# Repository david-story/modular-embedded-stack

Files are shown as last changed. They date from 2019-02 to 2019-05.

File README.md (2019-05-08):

# modular-embedded-stack

Credit card sized modular embedded stackable boards that was designed for fun for a microprocessor / 
microcontroller class. Base board is a microcontroller board that supports a thru-hole or smd PIC18F45K20 chip,
depending on which board you select. Daughter boards that are currently implemented have sensors and peripheals
that the user can interact with. 

The following is current included in the files:
- Board and schematic for thru-hole microcontroller
- Board and schematic for SMD microcontroller
- Board and schematic sensor daughter board

The following will be created in the future:
- Board and schematic for communication daughter board
- Other daughter boards and modules.

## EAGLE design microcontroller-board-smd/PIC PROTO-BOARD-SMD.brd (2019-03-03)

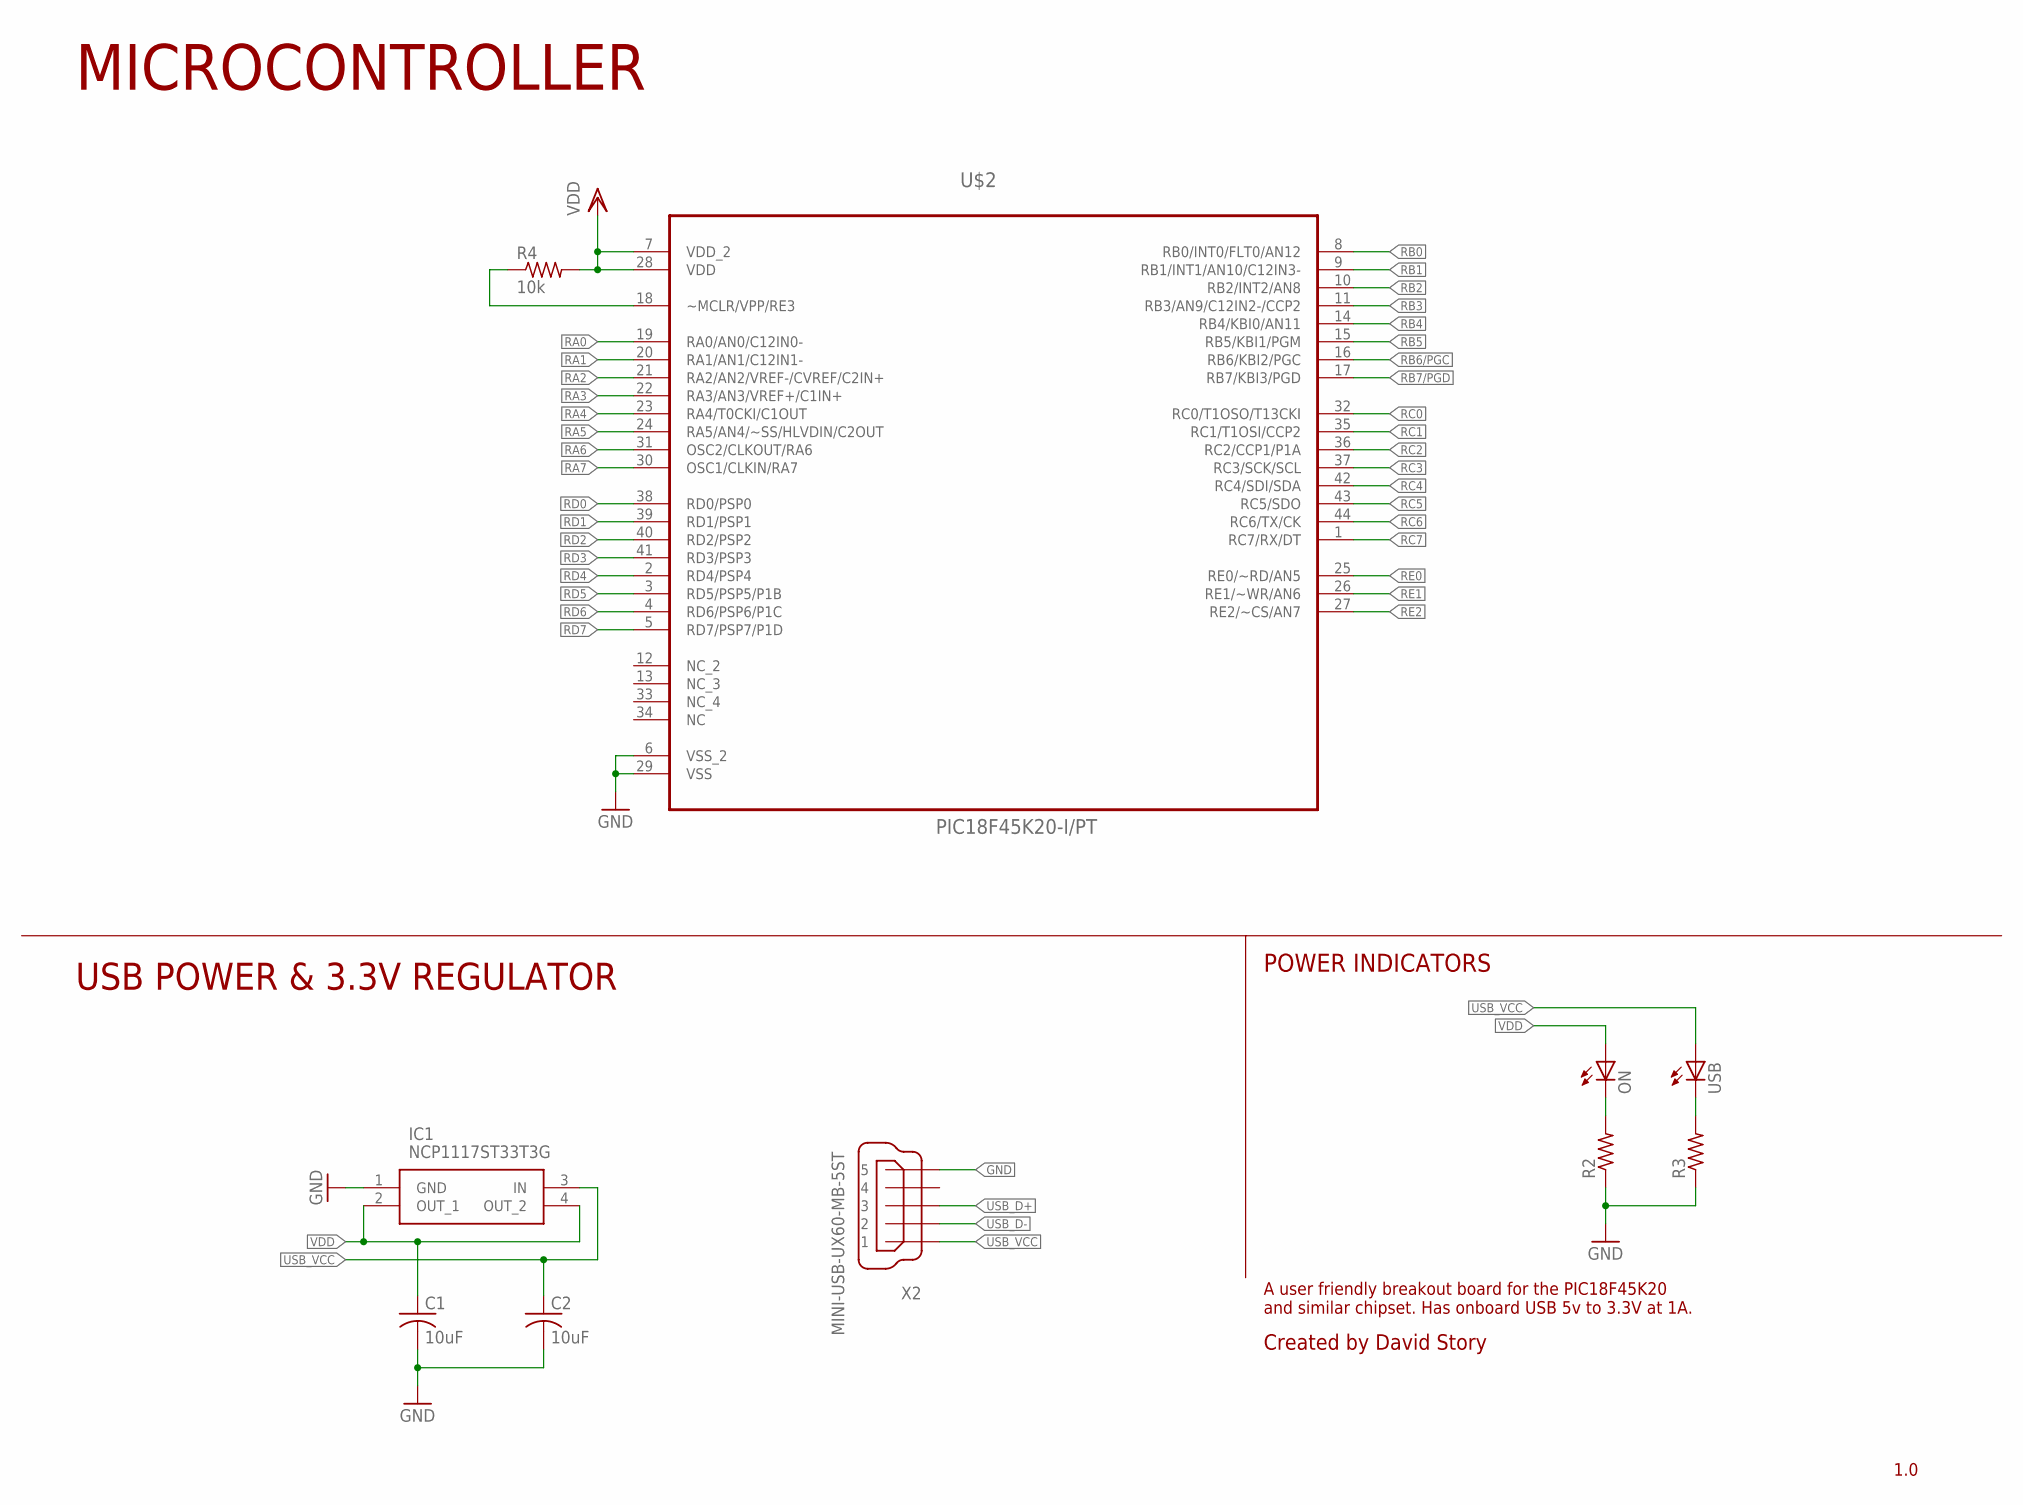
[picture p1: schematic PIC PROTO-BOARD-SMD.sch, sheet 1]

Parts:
C1, C2: 10uF; C0805
IC1: NCP1117ST33T3G; SOT230P700X180-4N
ON: LEDCHIP-LED0603; CHIP-LED0603
R2, R3: R-US_R0603; R0603
R4: 10k; R0805
U$2: PIC18F45K20-I/PT; QFP80P1200X1200X120-44N
USB: LEDCHIP-LED0603; CHIP-LED0603
X2: MINI-USB-UX60-MB-5ST; UX60-MB-5ST

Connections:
GND: C1.2, C2.2, IC1.1 (GND), R2.1, R3.1, U$2.6 (VSS_2), U$2.29 (VSS), X2.5; also elsewhere on the board
MCLR: R4.1, U$2.18 (~MCLR/VPP/RE3); also elsewhere on the board
ON_CATHODE: ON.C, R2.2
RA0: U$2.19 (RA0/AN0/C12IN0-); also elsewhere on the board
RA1: U$2.20 (RA1/AN1/C12IN1-); also elsewhere on the board
RA2: U$2.21 (RA2/AN2/VREF-/CVREF/C2IN+); also elsewhere on the board
RA3: U$2.22 (RA3/AN3/VREF+/C1IN+); also elsewhere on the board
RA4: U$2.23 (RA4/T0CKI/C1OUT); also elsewhere on the board
RA5: U$2.24 (RA5/AN4/~SS/HLVDIN/C2OUT); also elsewhere on the board
RA6: U$2.31 (OSC2/CLKOUT/RA6); also elsewhere on the board
RA7: U$2.30 (OSC1/CLKIN/RA7); also elsewhere on the board
RB0: U$2.8 (RB0/INT0/FLT0/AN12); also elsewhere on the board
RB1: U$2.9 (RB1/INT1/AN10/C12IN3-); also elsewhere on the board
RB2: U$2.10 (RB2/INT2/AN8); also elsewhere on the board
RB3: U$2.11 (RB3/AN9/C12IN2-/CCP2); also elsewhere on the board
RB4: U$2.14 (RB4/KBI0/AN11); also elsewhere on the board
RB5: U$2.15 (RB5/KBI1/PGM); also elsewhere on the board
RB6/PGC: U$2.16 (RB6/KBI2/PGC); also elsewhere on the board
RB7/PGD: U$2.17 (RB7/KBI3/PGD); also elsewhere on the board
RC0: U$2.32 (RC0/T1OSO/T13CKI); also elsewhere on the board
RC1: U$2.35 (RC1/T1OSI/CCP2); also elsewhere on the board
RC2: U$2.36 (RC2/CCP1/P1A); also elsewhere on the board
RC3: U$2.37 (RC3/SCK/SCL); also elsewhere on the board
RC4: U$2.42 (RC4/SDI/SDA); also elsewhere on the board
RC5: U$2.43 (RC5/SDO); also elsewhere on the board
RC6: U$2.44 (RC6/TX/CK); also elsewhere on the board
RC7: U$2.1 (RC7/RX/DT); also elsewhere on the board
RD0: U$2.38 (RD0/PSP0); also elsewhere on the board
RD1: U$2.39 (RD1/PSP1); also elsewhere on the board
RD2: U$2.40 (RD2/PSP2); also elsewhere on the board
RD3: U$2.41 (RD3/PSP3); also elsewhere on the board
RD4: U$2.2 (RD4/PSP4); also elsewhere on the board
RD5: U$2.3 (RD5/PSP5/P1B); also elsewhere on the board
RD6: U$2.4 (RD6/PSP6/P1C); also elsewhere on the board
RD7: U$2.5 (RD7/PSP7/P1D); also elsewhere on the board
RE0: U$2.25 (RE0/~RD/AN5); also elsewhere on the board
RE1: U$2.26 (RE1/~WR/AN6); also elsewhere on the board
RE2: U$2.27 (RE2/~CS/AN7); also elsewhere on the board
USB_CATHODE: R3.2, USB.C
USB_D+: X2.3; also elsewhere on the board
USB_D-: X2.2; also elsewhere on the board
USB_VCC: C2.1, IC1.3 (IN), USB.A, X2.1; also elsewhere on the board
VDD: C1.1, IC1.2 (OUT_1), IC1.4 (OUT_2), ON.A, R4.2, U$2.7 (VDD_2), U$2.28 (VDD); also elsewhere on the board

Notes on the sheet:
Created by David Story
1.0
MICROCONTROLLER
USB POWER & 3.3V REGULATOR
POWER INDICATORS
A user friendly breakout board for the PIC18F45K20 and similar chipset. Has onboard USB 5v to 3.3V at 1A.

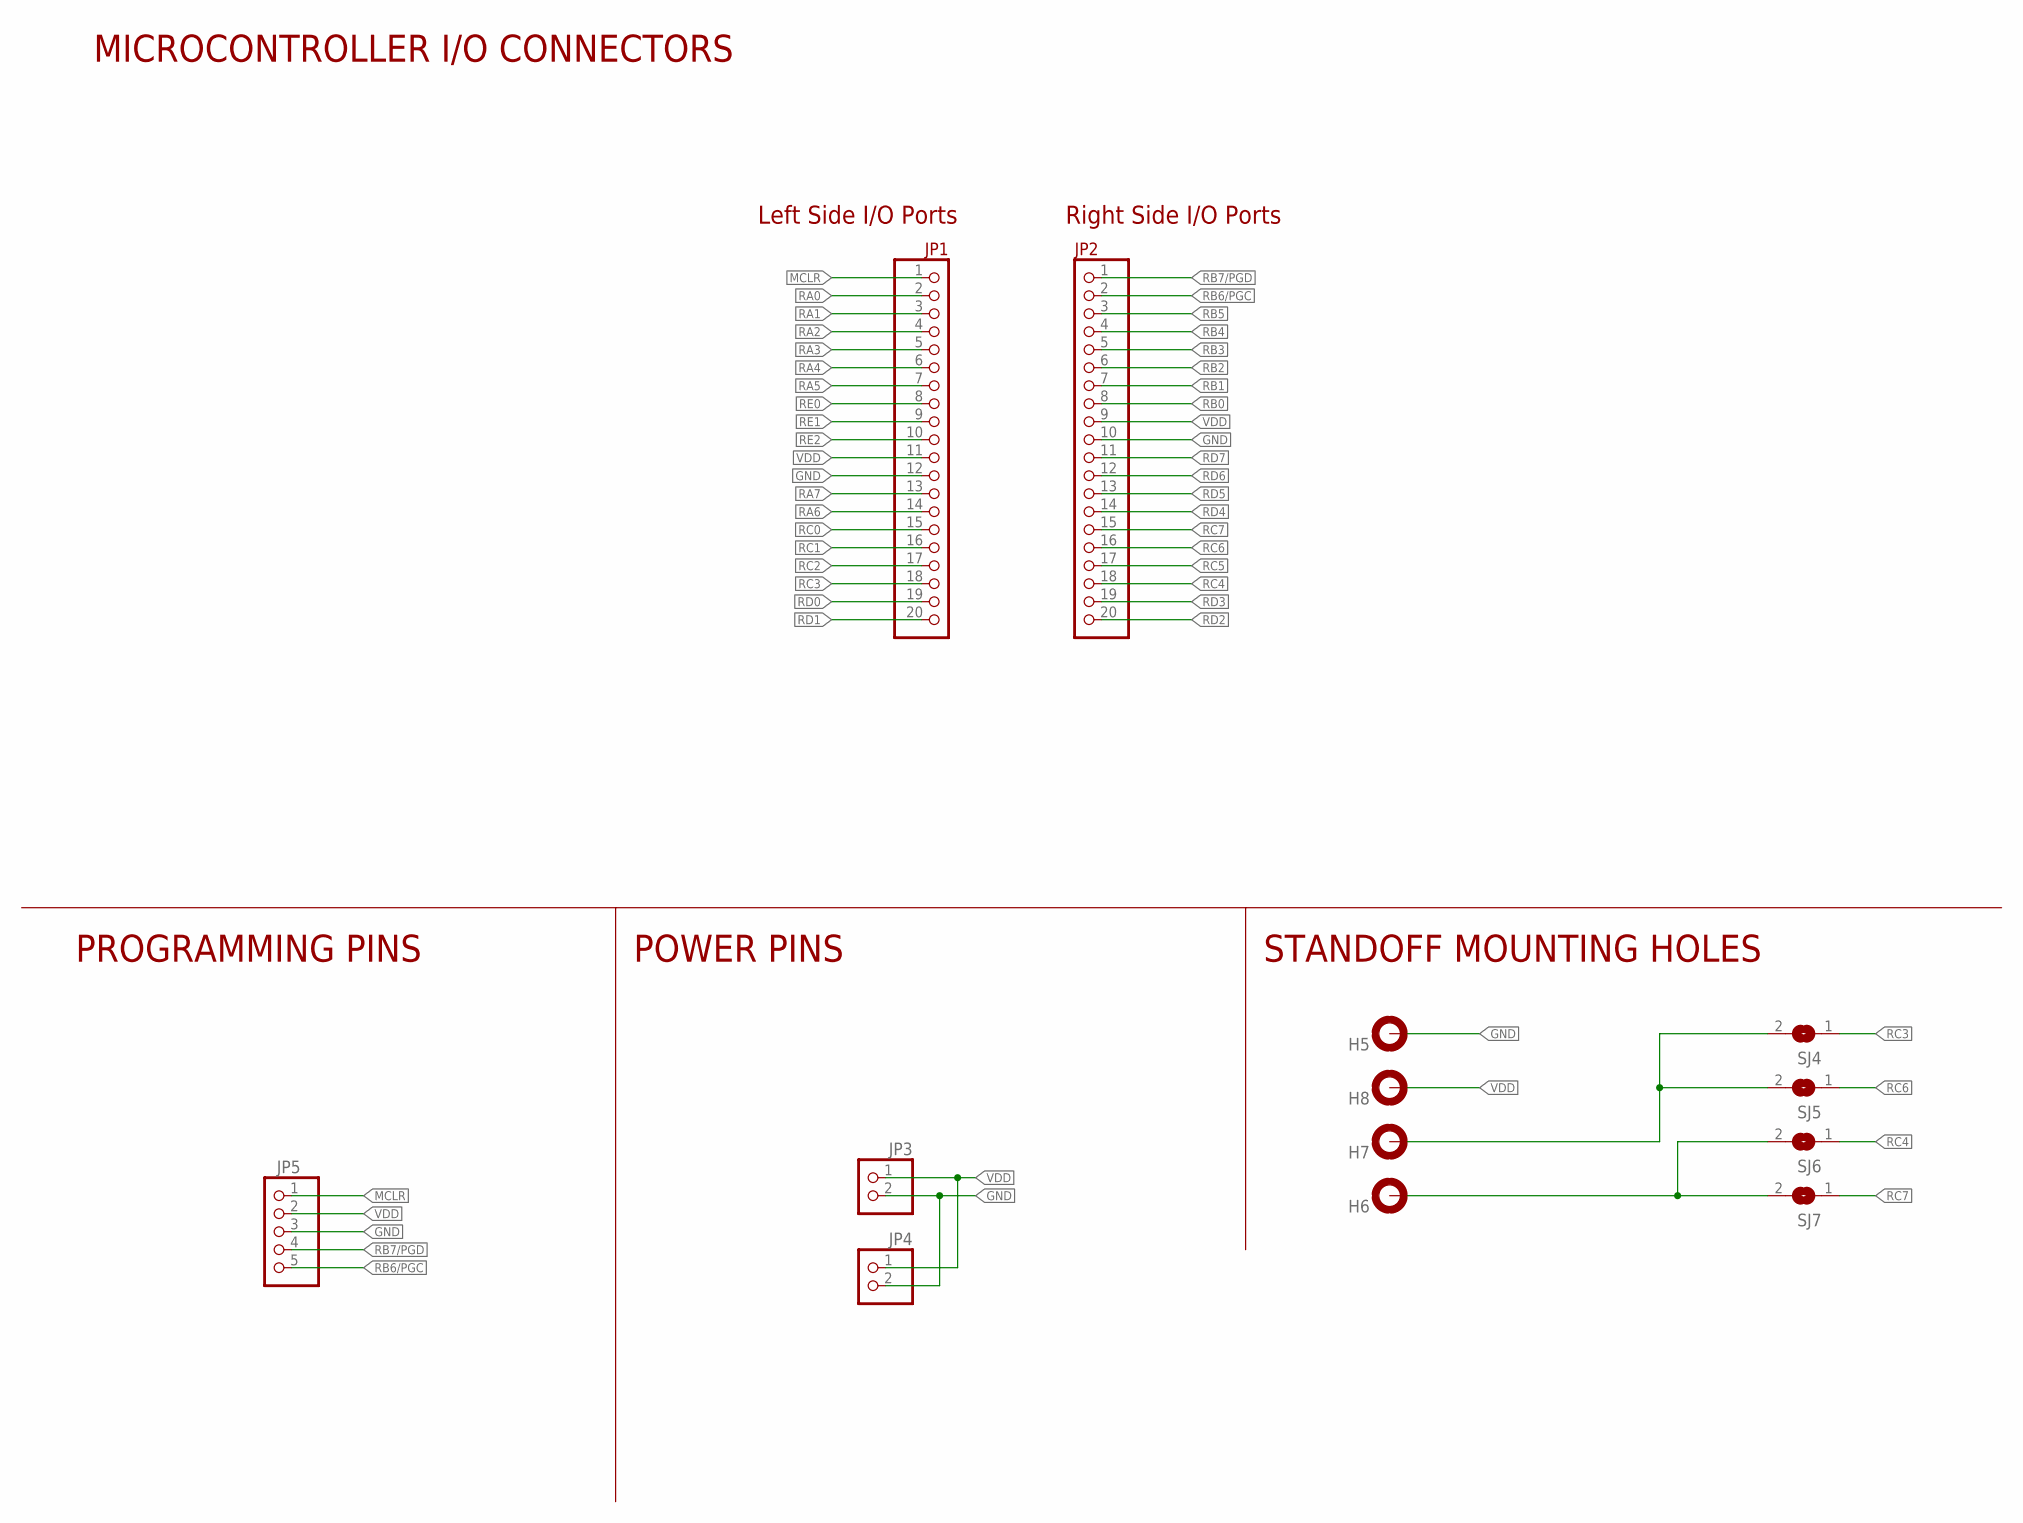
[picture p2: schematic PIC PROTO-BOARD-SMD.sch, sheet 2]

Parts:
H5, H6, H7, H8: MOUNT-PAD-ROUND3.3; 3,3-PAD
JP1, JP2: PINHD-1X20; 1X20
JP3, JP4: PINHD-1X2; 1X02
JP5: PINHD-1X5; 1X05
SJ4, SJ5, SJ6, SJ7: SJ

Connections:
COM_HOLE_1: H7.B3,3, SJ4.2, SJ5.2
COM_HOLE_2: H6.B3,3, SJ6.2, SJ7.2
GND: H5.B3,3, JP1.12, JP2.10, JP3.2, JP4.2, JP5.3; also elsewhere on the board
MCLR: JP1.1, JP5.1; also elsewhere on the board
RA0: JP1.2; also elsewhere on the board
RA1: JP1.3; also elsewhere on the board
RA2: JP1.4; also elsewhere on the board
RA3: JP1.5; also elsewhere on the board
RA4: JP1.6; also elsewhere on the board
RA5: JP1.7; also elsewhere on the board
RA6: JP1.14; also elsewhere on the board
RA7: JP1.13; also elsewhere on the board
RB0: JP2.8; also elsewhere on the board
RB1: JP2.7; also elsewhere on the board
RB2: JP2.6; also elsewhere on the board
RB3: JP2.5; also elsewhere on the board
RB4: JP2.4; also elsewhere on the board
RB5: JP2.3; also elsewhere on the board
RB6/PGC: JP2.2, JP5.5; also elsewhere on the board
RB7/PGD: JP2.1, JP5.4; also elsewhere on the board
RC0: JP1.15; also elsewhere on the board
RC1: JP1.16; also elsewhere on the board
RC2: JP1.17; also elsewhere on the board
RC3: JP1.18, SJ4.1; also elsewhere on the board
RC4: JP2.18, SJ6.1; also elsewhere on the board
RC5: JP2.17; also elsewhere on the board
RC6: JP2.16, SJ5.1; also elsewhere on the board
RC7: JP2.15, SJ7.1; also elsewhere on the board
RD0: JP1.19; also elsewhere on the board
RD1: JP1.20; also elsewhere on the board
RD2: JP2.20; also elsewhere on the board
RD3: JP2.19; also elsewhere on the board
RD4: JP2.14; also elsewhere on the board
RD5: JP2.13; also elsewhere on the board
RD6: JP2.12; also elsewhere on the board
RD7: JP2.11; also elsewhere on the board
RE0: JP1.8; also elsewhere on the board
RE1: JP1.9; also elsewhere on the board
RE2: JP1.10; also elsewhere on the board
VDD: H8.B3,3, JP1.11, JP2.9, JP3.1, JP4.1, JP5.2; also elsewhere on the board

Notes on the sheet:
Left Side I/O Ports
Right Side I/O Ports
PROGRAMMING PINS
POWER PINS
STANDOFF MOUNTING HOLES
MICROCONTROLLER I/O CONNECTORS

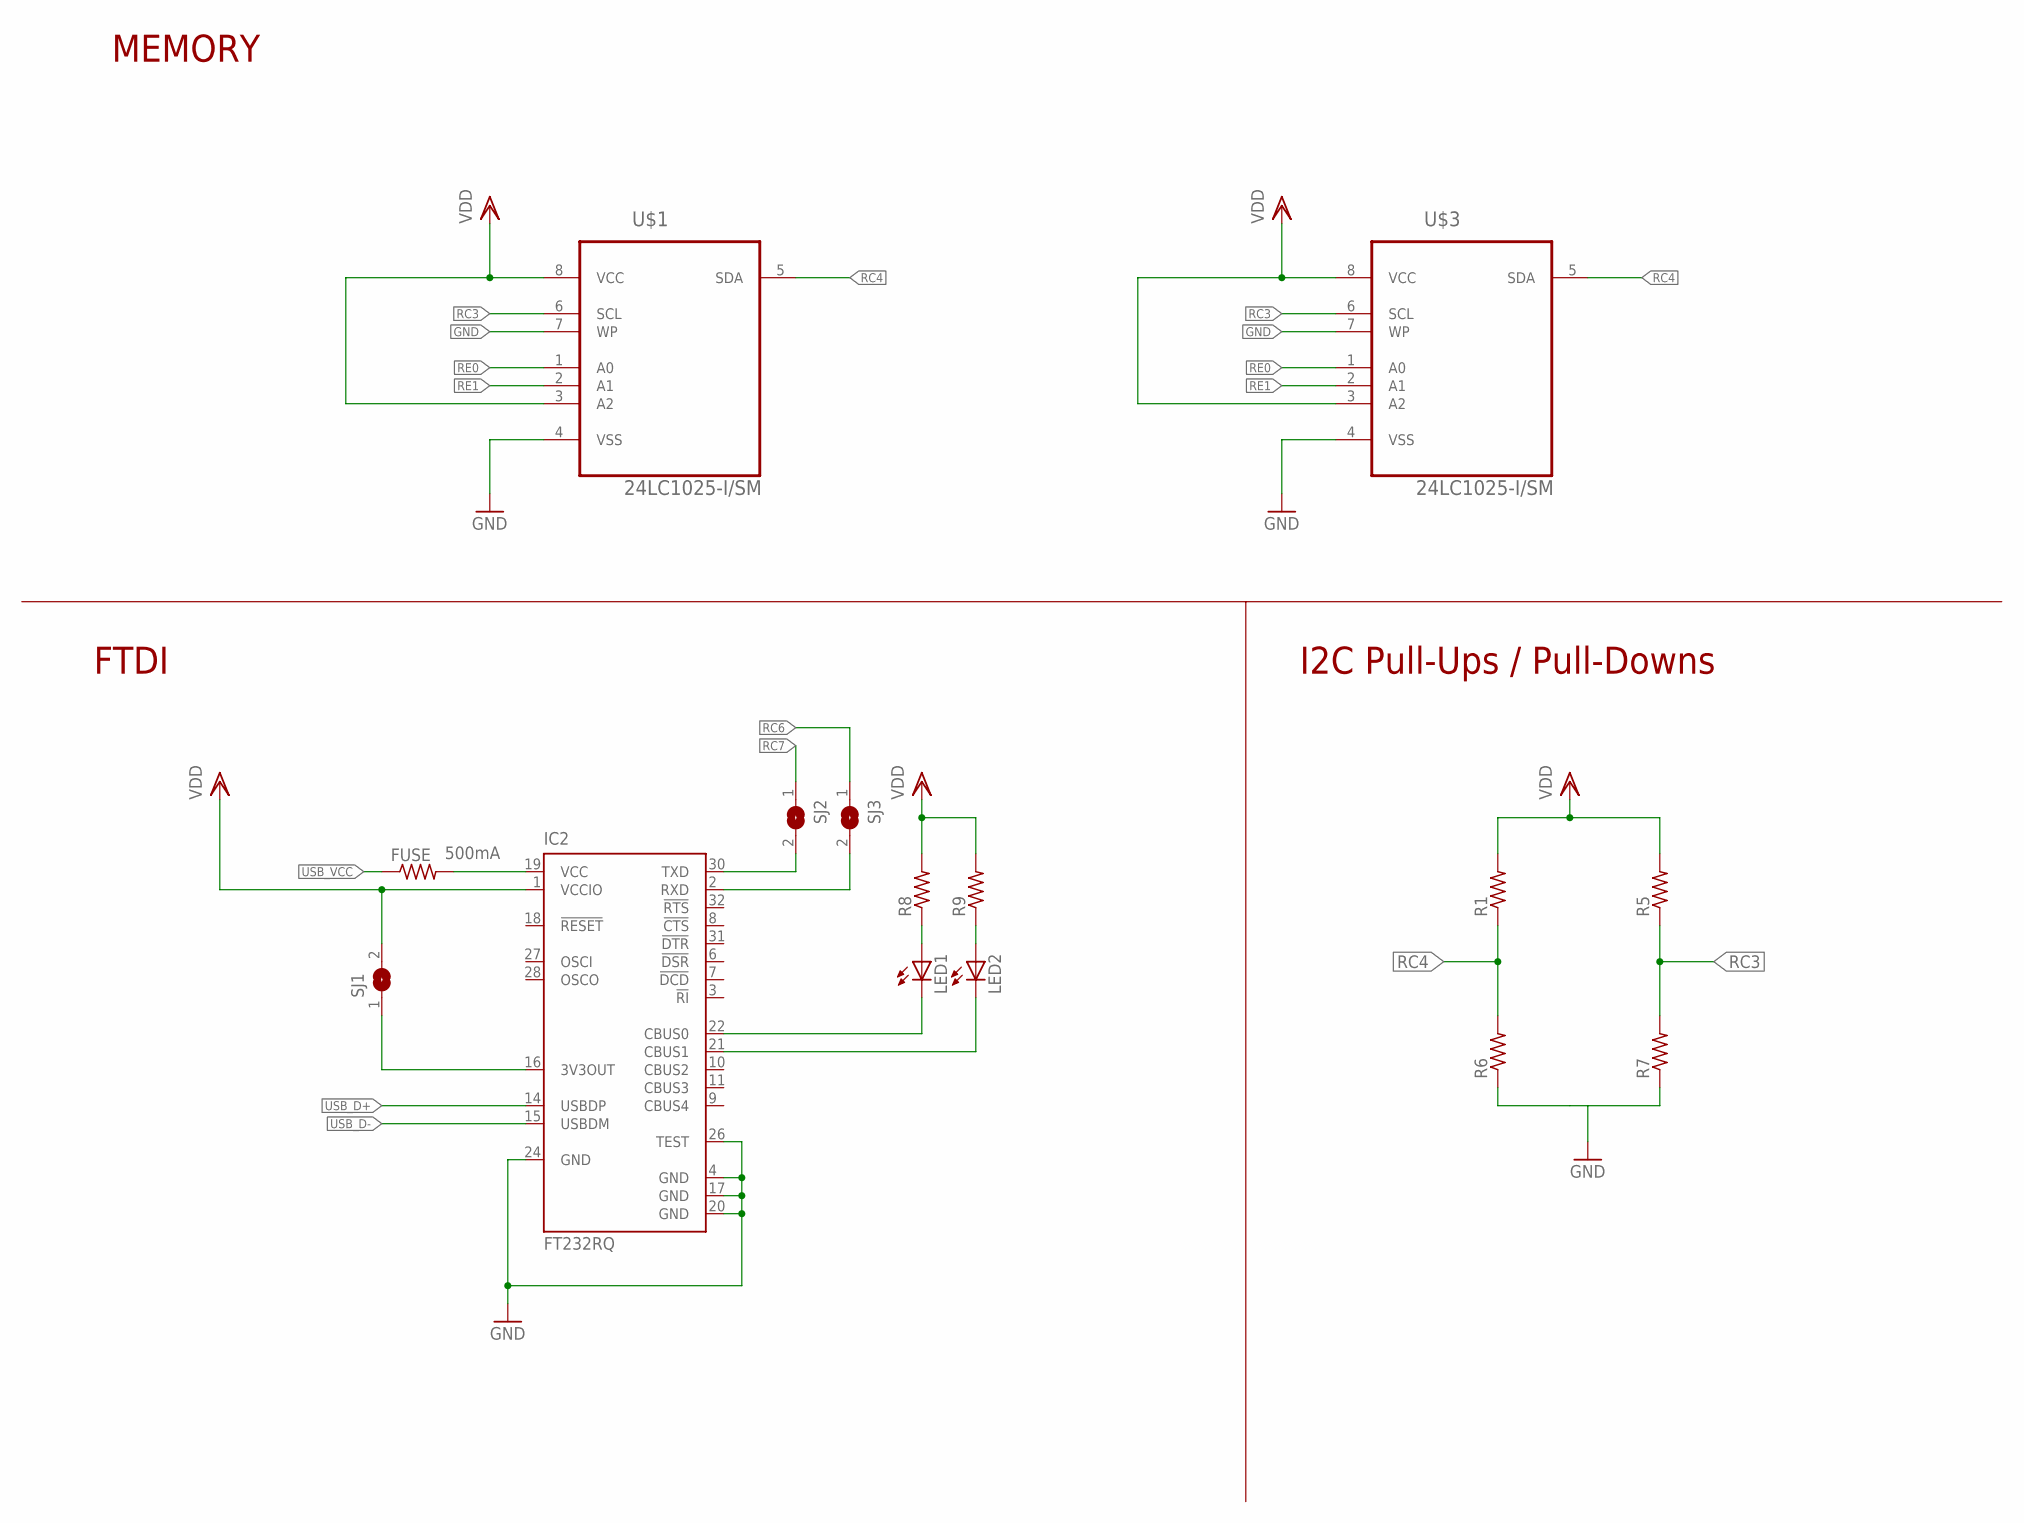
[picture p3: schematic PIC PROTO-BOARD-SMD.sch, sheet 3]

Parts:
FUSE: 500mA; M0805
IC2: FT232RQ; QFN32
LED1, LED2: LEDSML0603; SML0603
R1, R5, R6, R7, R8, R9: R-US_R0805; R0805
SJ1, SJ2, SJ3: SJ
U$1, U$3: 24LC1025-I/SM; SOIC127P794X203-8N

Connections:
3V3OUT: IC2.16 (3V3OUT), SJ1.1
FUSE_TO_FTDI: FUSE.2, IC2.19 (VCC)
GND: IC2.4 (GND), IC2.17 (GND), IC2.20 (GND), IC2.24 (GND), IC2.26 (TEST), R6.1, R7.1, U$1.4 (VSS), U$1.7 (WP), U$3.4 (VSS), U$3.7 (WP); also elsewhere on the board
LEDTX: LED1.A, R8.1
RC3: R5.1, R7.2, U$1.6 (SCL), U$3.6 (SCL); also elsewhere on the board
RC4: R1.1, R6.2, U$1.5 (SDA), U$3.5 (SDA); also elsewhere on the board
RC6: SJ3.1; also elsewhere on the board
RC7: SJ2.1; also elsewhere on the board
RE0: U$1.1 (A0), U$3.1 (A0); also elsewhere on the board
RE1: U$1.2 (A1), U$3.2 (A1); also elsewhere on the board
RXD: IC2.2 (RXD), SJ3.2
RXLED: LED2.A, R9.1
RX_LED: IC2.21 (CBUS1), LED2.C
TXD: IC2.30 (TXD), SJ2.2
TX_LED: IC2.22 (CBUS0), LED1.C
USB_D+: IC2.14 (USBDP); also elsewhere on the board
USB_D-: IC2.15 (USBDM); also elsewhere on the board
USB_VCC: FUSE.1; also elsewhere on the board
VDD: IC2.1 (VCCIO), R1.2, R5.2, R8.2, R9.2, SJ1.2, U$1.3 (A2), U$1.8 (VCC), U$3.3 (A2), U$3.8 (VCC); also elsewhere on the board

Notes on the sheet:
MEMORY
I2C Pull-Ups / Pull-Downs
FTDI

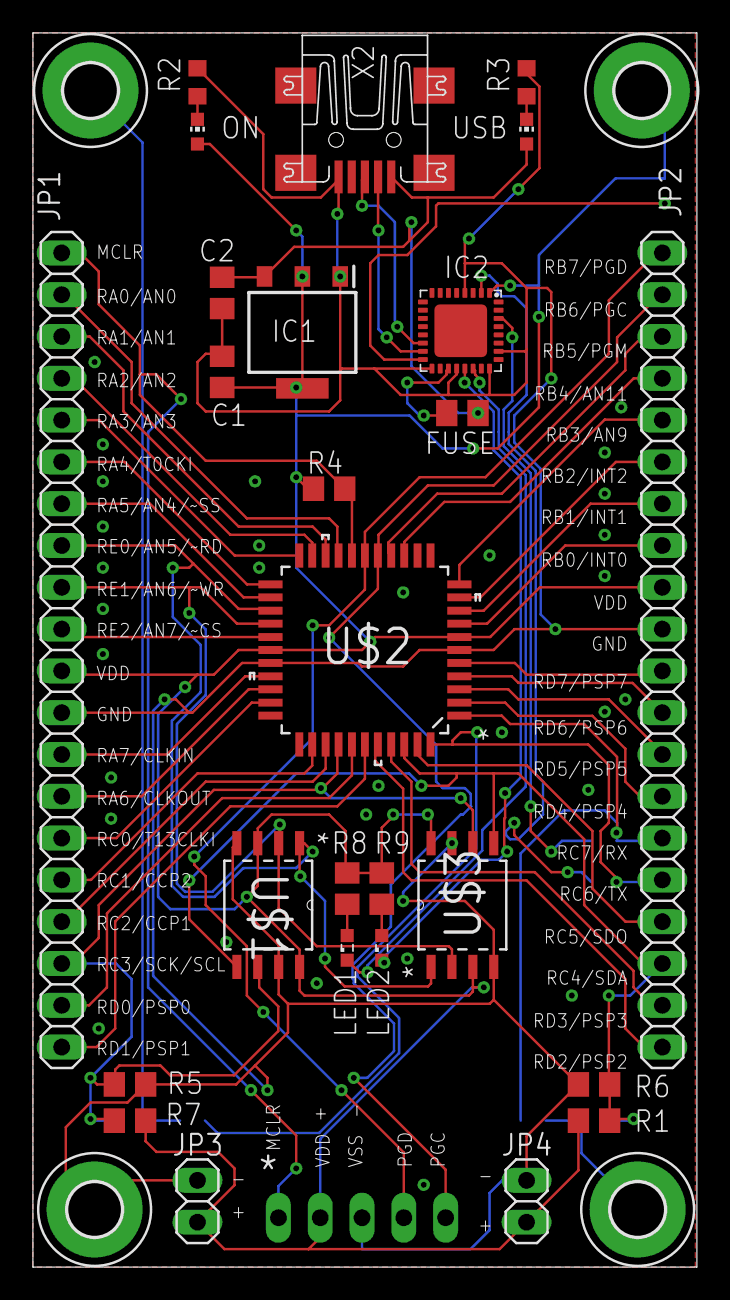
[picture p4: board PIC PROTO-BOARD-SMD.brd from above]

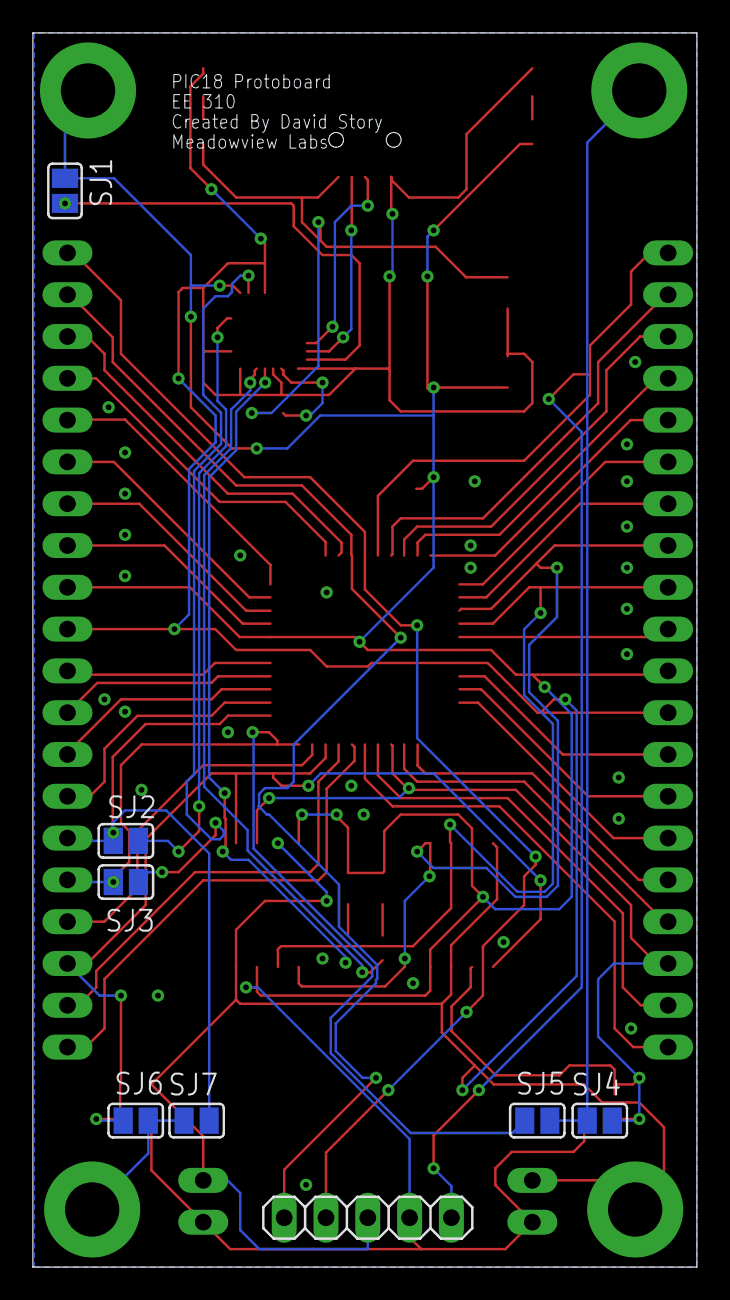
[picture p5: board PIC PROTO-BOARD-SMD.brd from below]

Board: 2 copper layers, 40.4 x 75.0 mm, 38 parts (8 on the bottom side), 53 nets.

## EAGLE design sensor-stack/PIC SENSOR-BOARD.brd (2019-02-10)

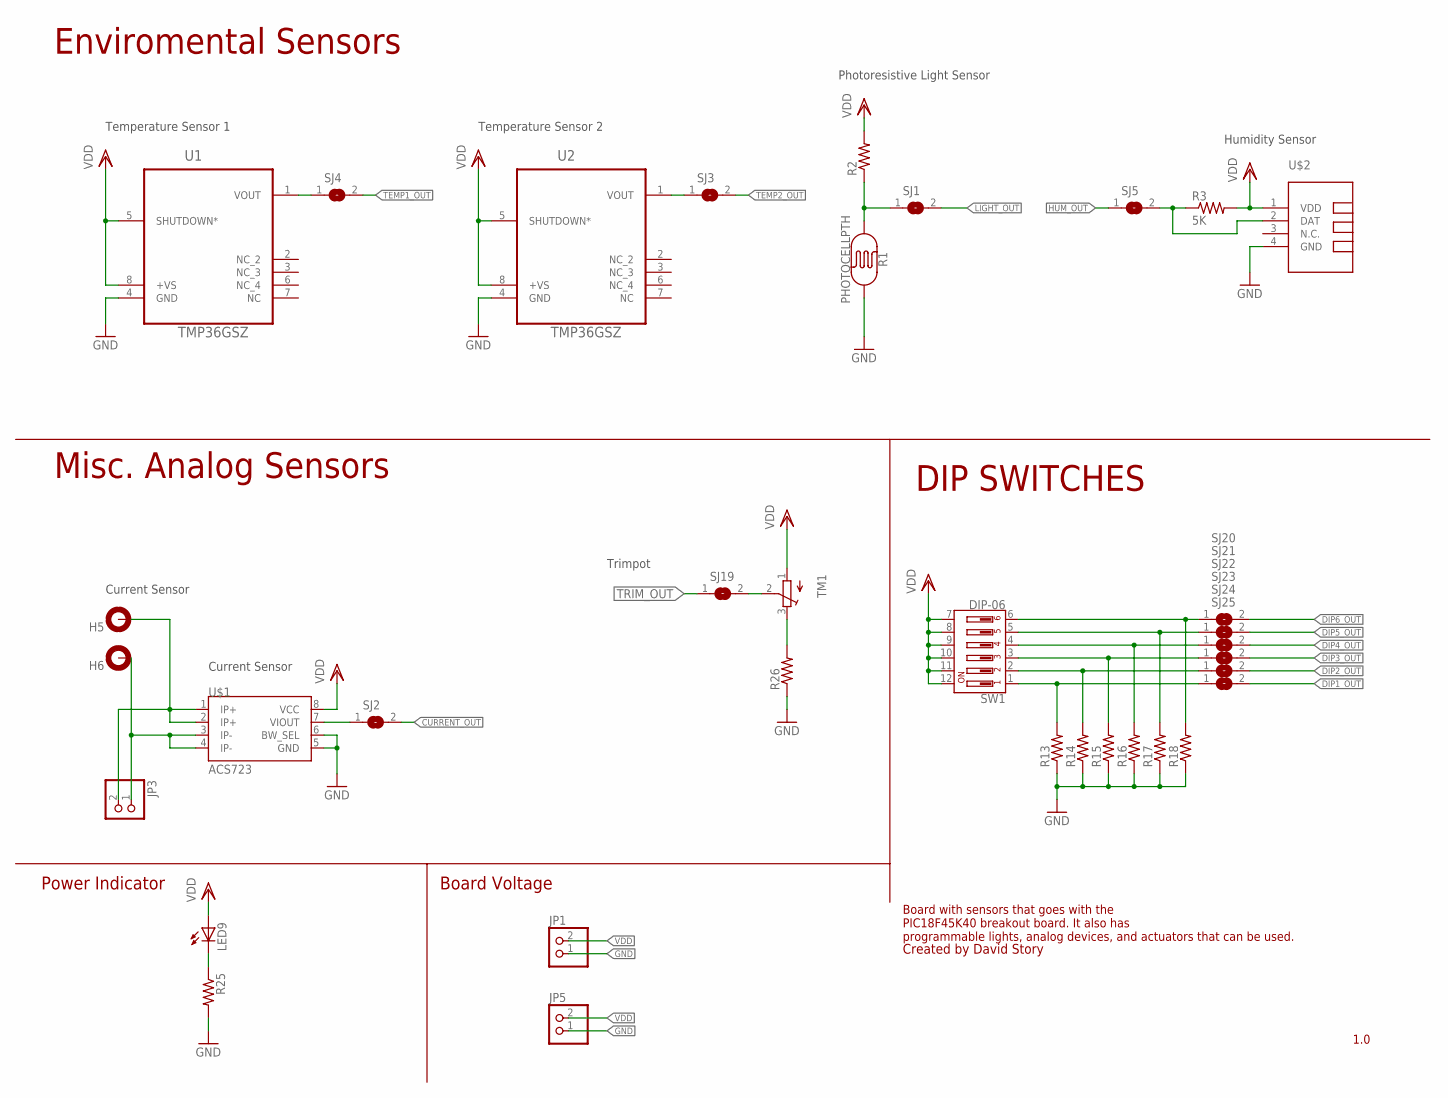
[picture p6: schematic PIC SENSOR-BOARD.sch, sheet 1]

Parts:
H5, H6: MOUNT-PAD-ROUND3.3; 3,3-PAD
JP1, JP3, JP5: PINHD-1X2; 1X02
LED9: LEDCHIPLED_0603; CHIPLED_0603
R1: PHOTOCELLPTH; PHOTOCELL
R2, R25, R26: R-US_M0805; M0805
R3: 5K; M0805
R13, R14, R15, R16, R17, R18: R-US_R0805; R0805
SJ1, SJ2, SJ3, SJ4, SJ5, SJ19, SJ20, SJ21, SJ22, SJ23, SJ24, SJ25: SJ
SW1: DIP-06; DIPSWITCH-06-SMD
TM1: TRIMPOT3386; TRIM-3386
U1, U2: TMP36GSZ; SOIC127P600X175-8N
U$1: ACS723; SO08
U$2: TEMP-HUM-SENSOR-DHT11

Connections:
CURRENT_LINE: SJ2.1, U$1.7 (VIOUT)
CURRENT_OUT: SJ2.2; also elsewhere on the board
DIP1_LINE: R13.2, SJ25.1, SW1.1
DIP1_OUT: SJ25.2; also elsewhere on the board
DIP2_LINE: R14.2, SJ24.1, SW1.2
DIP2_OUT: SJ24.2; also elsewhere on the board
DIP3_LINE: R15.2, SJ23.1, SW1.3
DIP3_OUT: SJ23.2; also elsewhere on the board
DIP4_LINE: R16.2, SJ22.1, SW1.4
DIP4_OUT: SJ22.2; also elsewhere on the board
DIP5_LINE: R17.2, SJ21.1, SW1.5
DIP5_OUT: SJ21.2; also elsewhere on the board
DIP6_LINE: R18.2, SJ20.1, SW1.6
DIP6_OUT: SJ20.2; also elsewhere on the board
GND: JP1.1, JP5.1, R1.2, R13.1, R14.1, R15.1, R16.1, R17.1, R18.1, R25.2, R26.1, U1.4 (GND), U2.4 (GND), U$1.5 (GND), U$1.6 (BW_SEL), U$2.4 (GND); also elsewhere on the board
HUM_DATA: R3.1, SJ5.2, U$2.2 (DAT)
HUM_OUT: SJ5.1; also elsewhere on the board
IP+: H5.B3,3, JP3.2, U$1.1 (IP+), U$1.2 (IP+)
IP-: H6.B3,3, JP3.1, U$1.3 (IP-), U$1.4 (IP-)
LIGHT_LINE: R1.1, R2.1, SJ1.1
LIGHT_OUT: SJ1.2; also elsewhere on the board
POWER-: LED9.C, R25.1
T1_LINE: SJ4.1, U1.1 (VOUT)
T2_LINE: SJ3.1, U2.1 (VOUT)
TEMP1_OUT: SJ4.2; also elsewhere on the board
TEMP2_OUT: SJ3.2; also elsewhere on the board
TRIM: R26.2, TM1.3 (E)
TRIM_JUMP: SJ19.2, TM1.2 (S)
TRIM_OUT: SJ19.1; also elsewhere on the board
VDD: JP1.2, JP5.2, LED9.A, R2.2, R3.2, SW1.7, SW1.8, SW1.9, SW1.10, SW1.11, SW1.12, TM1.1 (A), U1.5 (SHUTDOWN*), U1.8 (+VS), U2.5 (SHUTDOWN*), U2.8 (+VS), U$1.8 (VCC), U$2.1 (VDD); also elsewhere on the board

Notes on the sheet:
Created by David Story
1.0
Board with sensors that goes with the PIC18F45K40 breakout board. It also has programmable lights, analog devices, and actuators that can be used.
Misc. Analog Sensors
Enviromental Sensors
DIP SWITCHES
Temperature Sensor 1
Temperature Sensor 2
Photoresistive Light Sensor
Humidity Sensor
Current Sensor
Trimpot
Power Indicator
Board Voltage

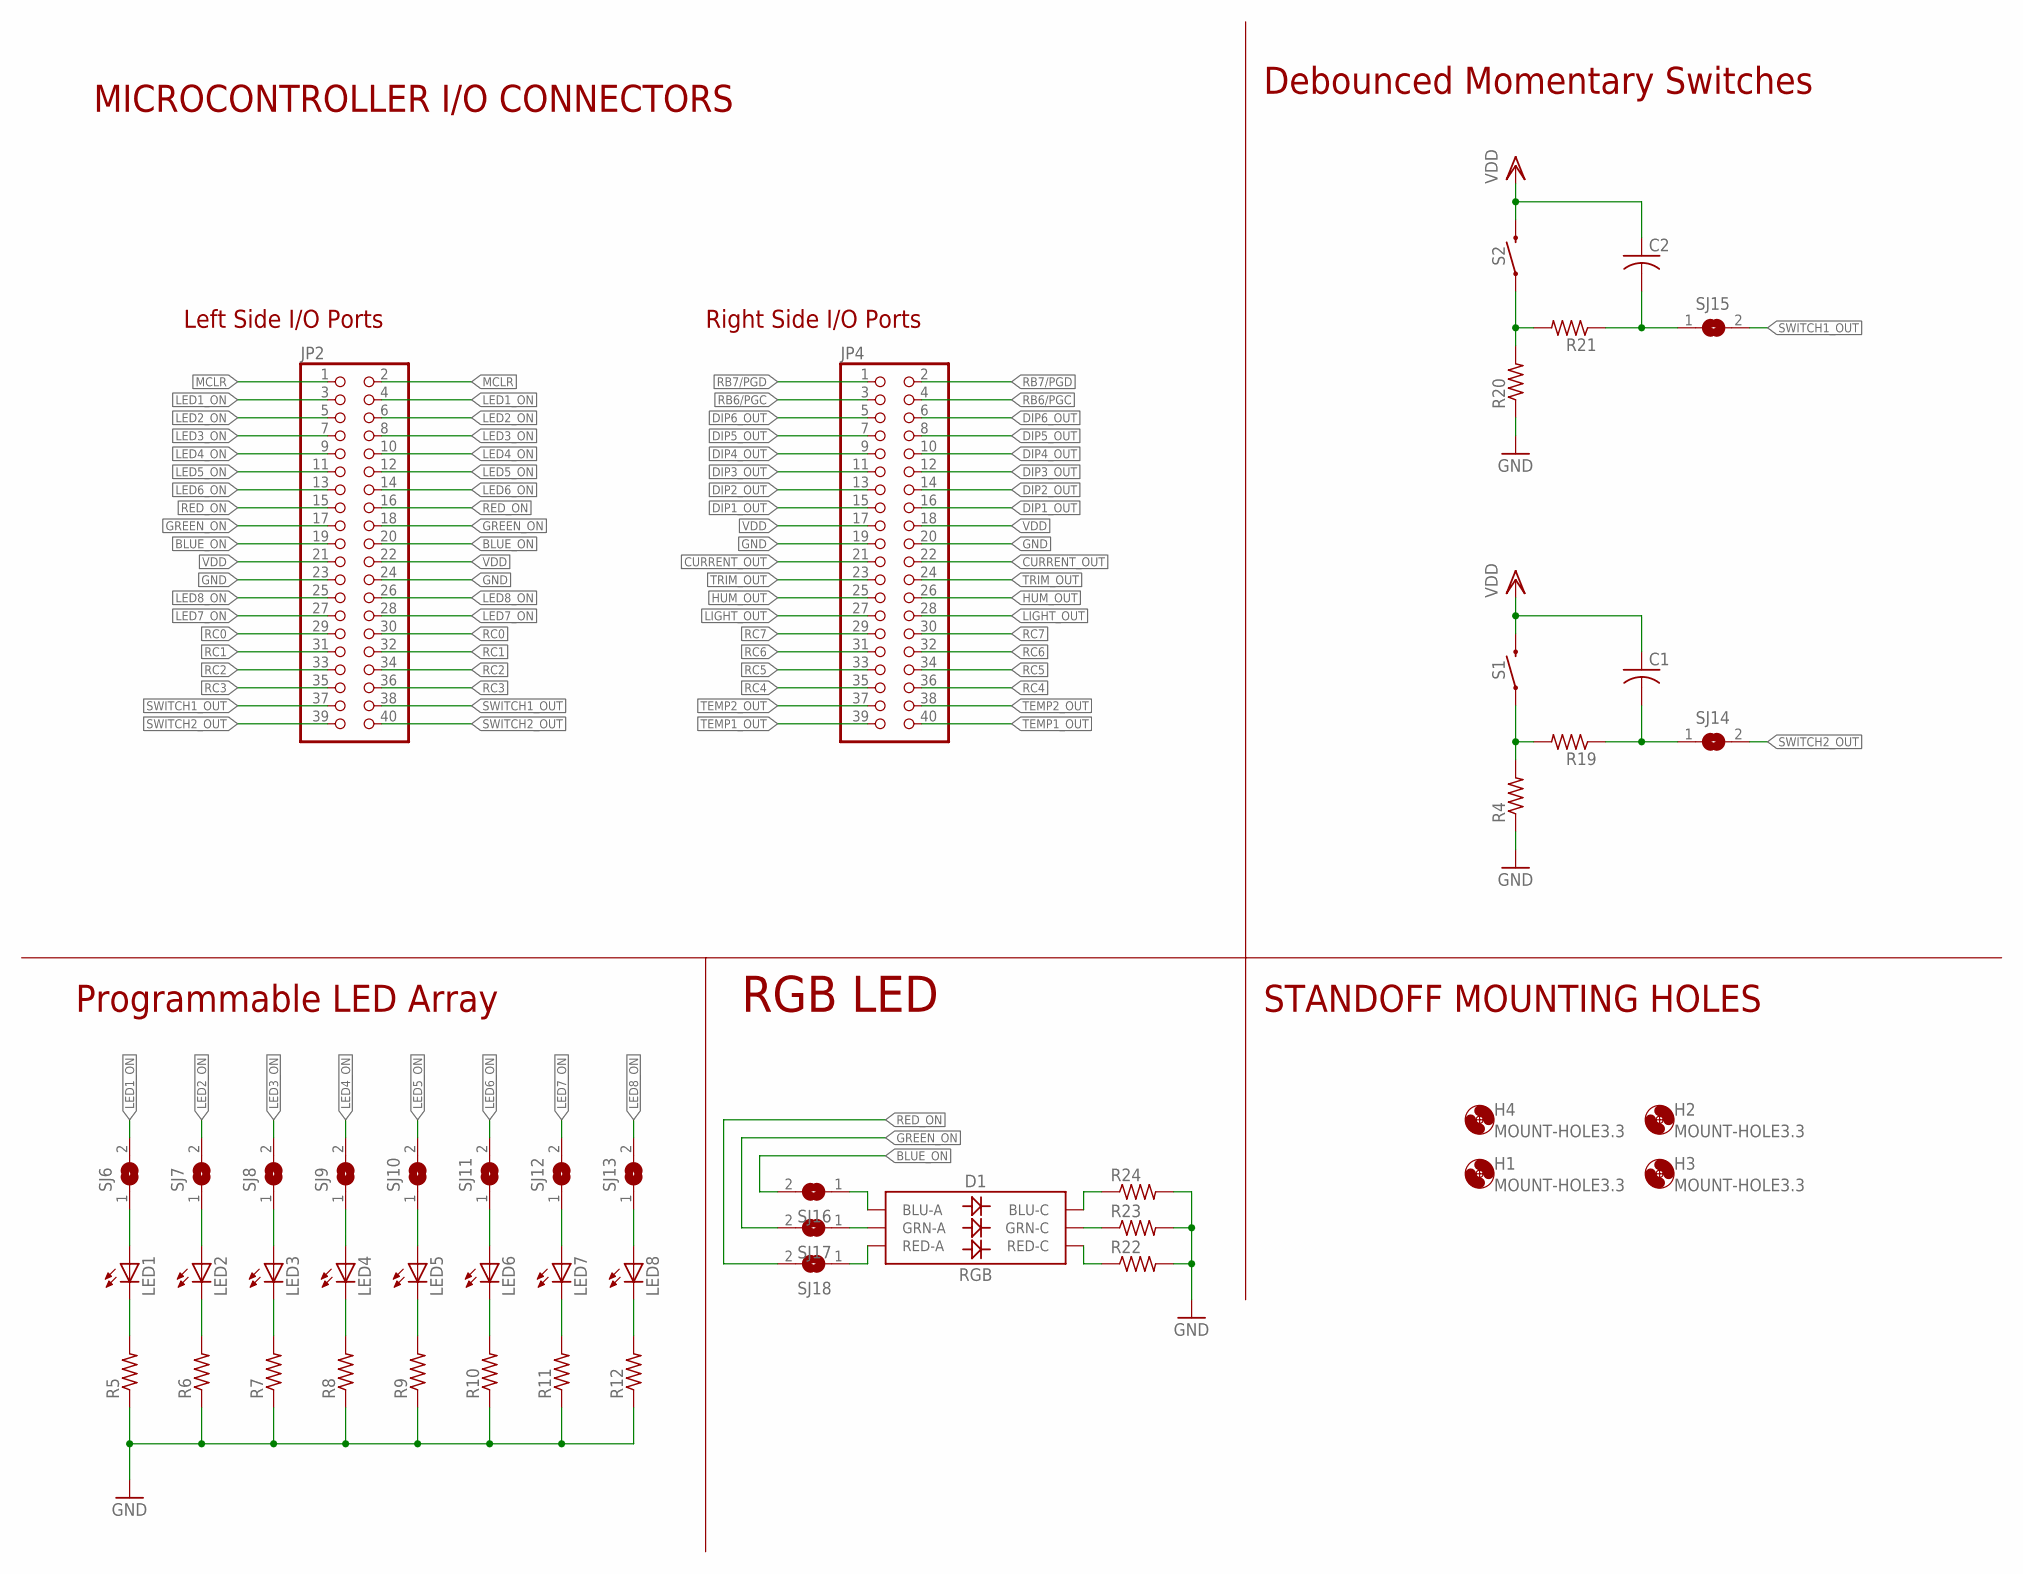
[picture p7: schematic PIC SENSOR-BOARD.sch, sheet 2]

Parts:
C1, C2: C-USC0805; C0805
D1: RGB; PLCC-6-LED
H1, H2, H3, H4: MOUNT-HOLE3.3; 3,3
JP2, JP4: PINHD-2X20; 2X20
LED1, LED2, LED3, LED4, LED5, LED6, LED7, LED8: LEDSML0603; SML0603
R4, R5, R6, R7, R8, R9, R10, R11, R12, R19, R20, R21: R-US_M0805; M0805
R22, R23, R24: R-US_R0805; R0805
S1, S2: MOMENTARY-SWITCH-SPST-PTH-6.0MM; TACTILE_SWITCH_PTH_6.0MM
SJ6, SJ7, SJ8, SJ9, SJ10, SJ11, SJ12, SJ13, SJ14, SJ15, SJ16, SJ17, SJ18: SJ

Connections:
BLUE+: D1.AB (BLU-A), SJ16.1
BLUE-: D1.CB (BLU-C), R24.1
BLUE_ON: JP2.19, JP2.20, SJ16.2
CAP2_NEG: C1.2, R19.1, SJ14.1
CAP_NEG: C2.2, R21.1, SJ15.1
CURRENT_OUT: JP4.21, JP4.22; also elsewhere on the board
DIP1_OUT: JP4.15, JP4.16; also elsewhere on the board
DIP2_OUT: JP4.13, JP4.14; also elsewhere on the board
DIP3_OUT: JP4.11, JP4.12; also elsewhere on the board
DIP4_OUT: JP4.9, JP4.10; also elsewhere on the board
DIP5_OUT: JP4.7, JP4.8; also elsewhere on the board
DIP6_OUT: JP4.5, JP4.6; also elsewhere on the board
GND: JP2.23, JP2.24, JP4.19, JP4.20, R4.1, R5.1, R6.1, R7.1, R8.1, R9.1, R10.1, R11.1, R12.1, R20.1, R22.2, R23.2, R24.2; also elsewhere on the board
GREEN+: D1.AG (GRN-A), SJ17.1
GREEN-: D1.CG (GRN-C), R23.1
GREEN_ON: JP2.17, JP2.18, SJ17.2
HUM_OUT: JP4.25, JP4.26; also elsewhere on the board
L1+: LED1.A, SJ6.1
L1-: LED1.C, R5.2
L2+: LED2.A, SJ7.1
L2-: LED2.C, R6.2
L3+: LED3.A, SJ8.1
L3-: LED3.C, R7.2
L4+: LED4.A, SJ9.1
L4-: LED4.C, R8.2
L5+: LED5.A, SJ10.1
L5-: LED5.C, R9.2
L6+: LED6.A, SJ11.1
L6-: LED6.C, R10.2
L7+: LED7.A, SJ12.1
L7-: LED7.C, R11.2
L8+: LED8.A, SJ13.1
L8-: LED8.C, R12.2
LED1_ON: JP2.3, JP2.4, SJ6.2
LED2_ON: JP2.5, JP2.6, SJ7.2
LED3_ON: JP2.7, JP2.8, SJ8.2
LED4_ON: JP2.9, JP2.10, SJ9.2
LED5_ON: JP2.11, JP2.12, SJ10.2
LED6_ON: JP2.13, JP2.14, SJ11.2
LED7_ON: JP2.27, JP2.28, SJ12.2
LED8_ON: JP2.25, JP2.26, SJ13.2
LIGHT_OUT: JP4.27, JP4.28; also elsewhere on the board
MCLR: JP2.1, JP2.2
RB6/PGC: JP4.3, JP4.4
RB7/PGD: JP4.1, JP4.2
RC0: JP2.29, JP2.30
RC1: JP2.31, JP2.32
RC2: JP2.33, JP2.34
RC3: JP2.35, JP2.36
RC4: JP4.35, JP4.36
RC5: JP4.33, JP4.34
RC6: JP4.31, JP4.32
RC7: JP4.29, JP4.30
RED+: D1.AR (RED-A), SJ18.1
RED-: D1.CR (RED-C), R22.1
RED_ON: JP2.15, JP2.16, SJ18.2
SWITCH1_OUT: JP2.37, JP2.38, SJ15.2
SWITCH2_OUT: JP2.39, JP2.40, SJ14.2
SW_NEG: R20.2, R21.2, S2.1
SW_NEG2: R4.2, R19.2, S1.1
TEMP1_OUT: JP4.39, JP4.40; also elsewhere on the board
TEMP2_OUT: JP4.37, JP4.38; also elsewhere on the board
TRIM_OUT: JP4.23, JP4.24; also elsewhere on the board
VDD: C1.1, C2.1, JP2.21, JP2.22, JP4.17, JP4.18, S1.3 (2), S2.3 (2); also elsewhere on the board

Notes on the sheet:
Left Side I/O Ports
Right Side I/O Ports
Programmable LED Array
STANDOFF MOUNTING HOLES
MICROCONTROLLER I/O CONNECTORS
Debounced Momentary Switches
RGB LED

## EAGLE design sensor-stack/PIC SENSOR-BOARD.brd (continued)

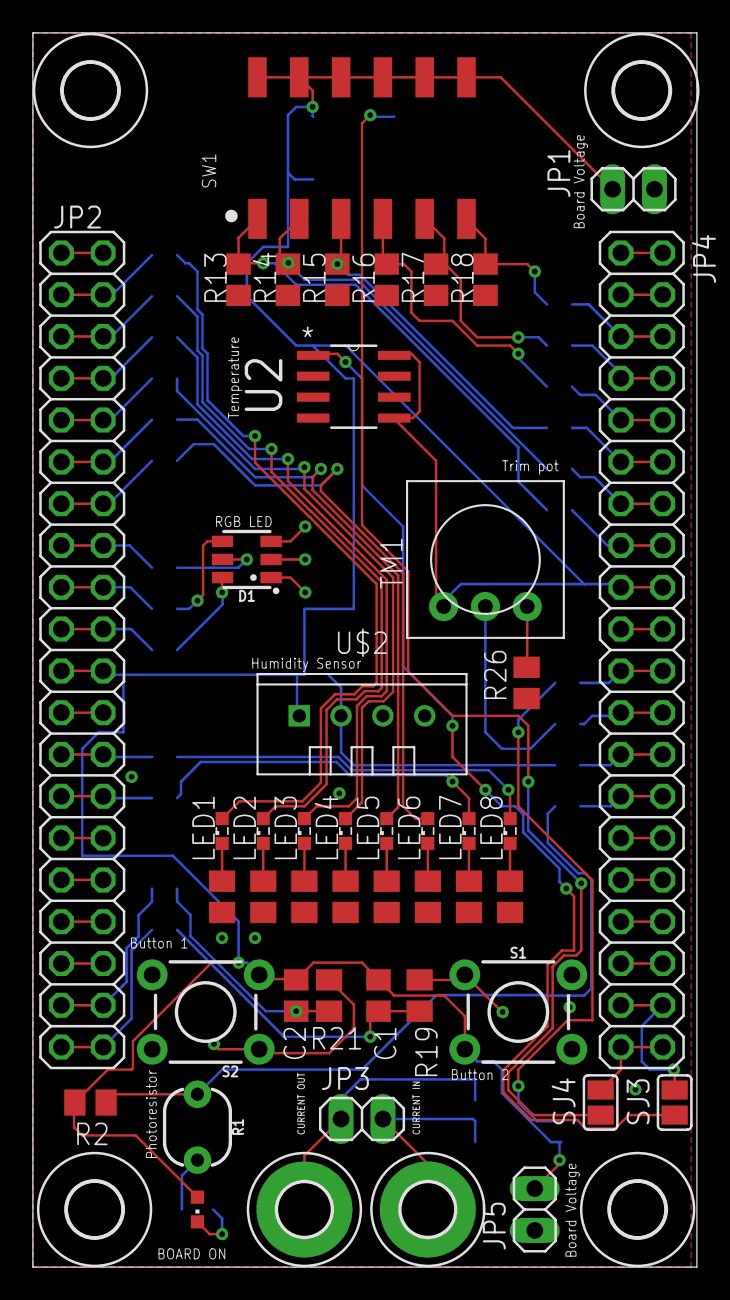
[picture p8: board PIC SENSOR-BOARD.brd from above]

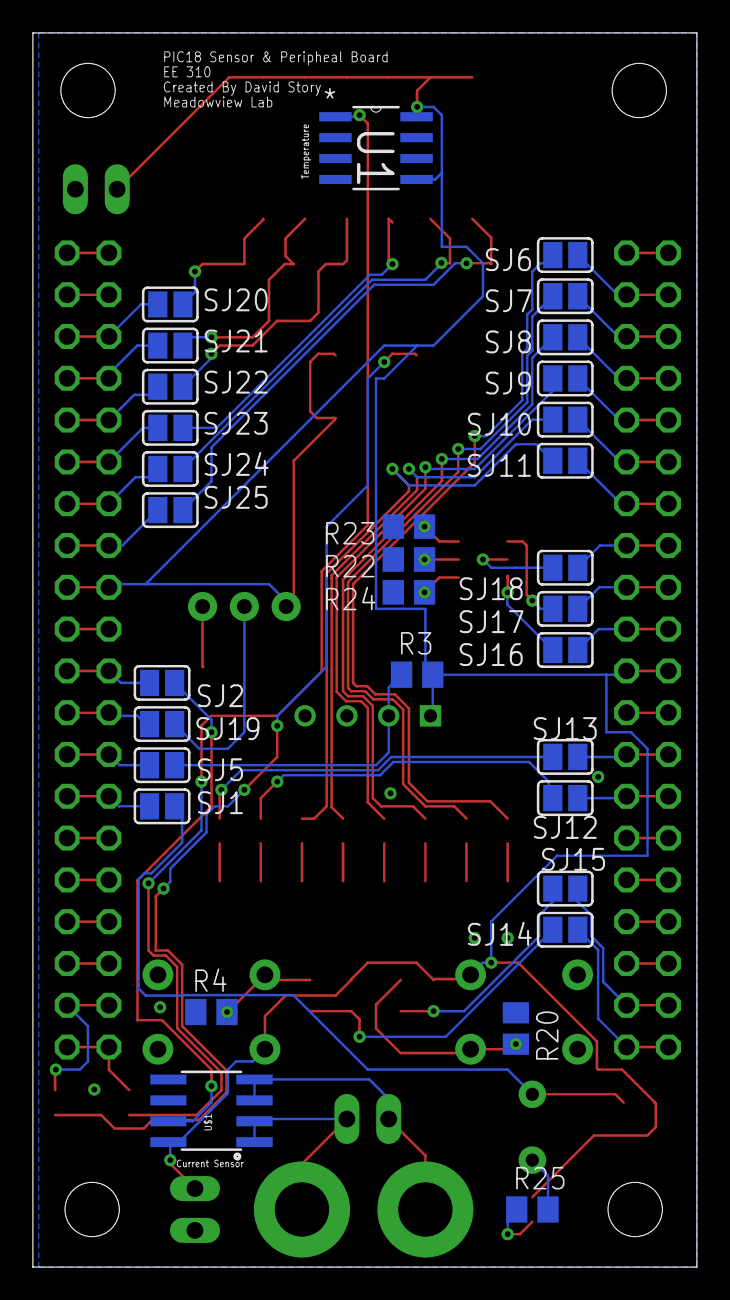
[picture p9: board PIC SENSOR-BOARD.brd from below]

Board: 2 copper layers, 40.4 x 75.0 mm, 82 parts (32 on the bottom side), 80 nets.

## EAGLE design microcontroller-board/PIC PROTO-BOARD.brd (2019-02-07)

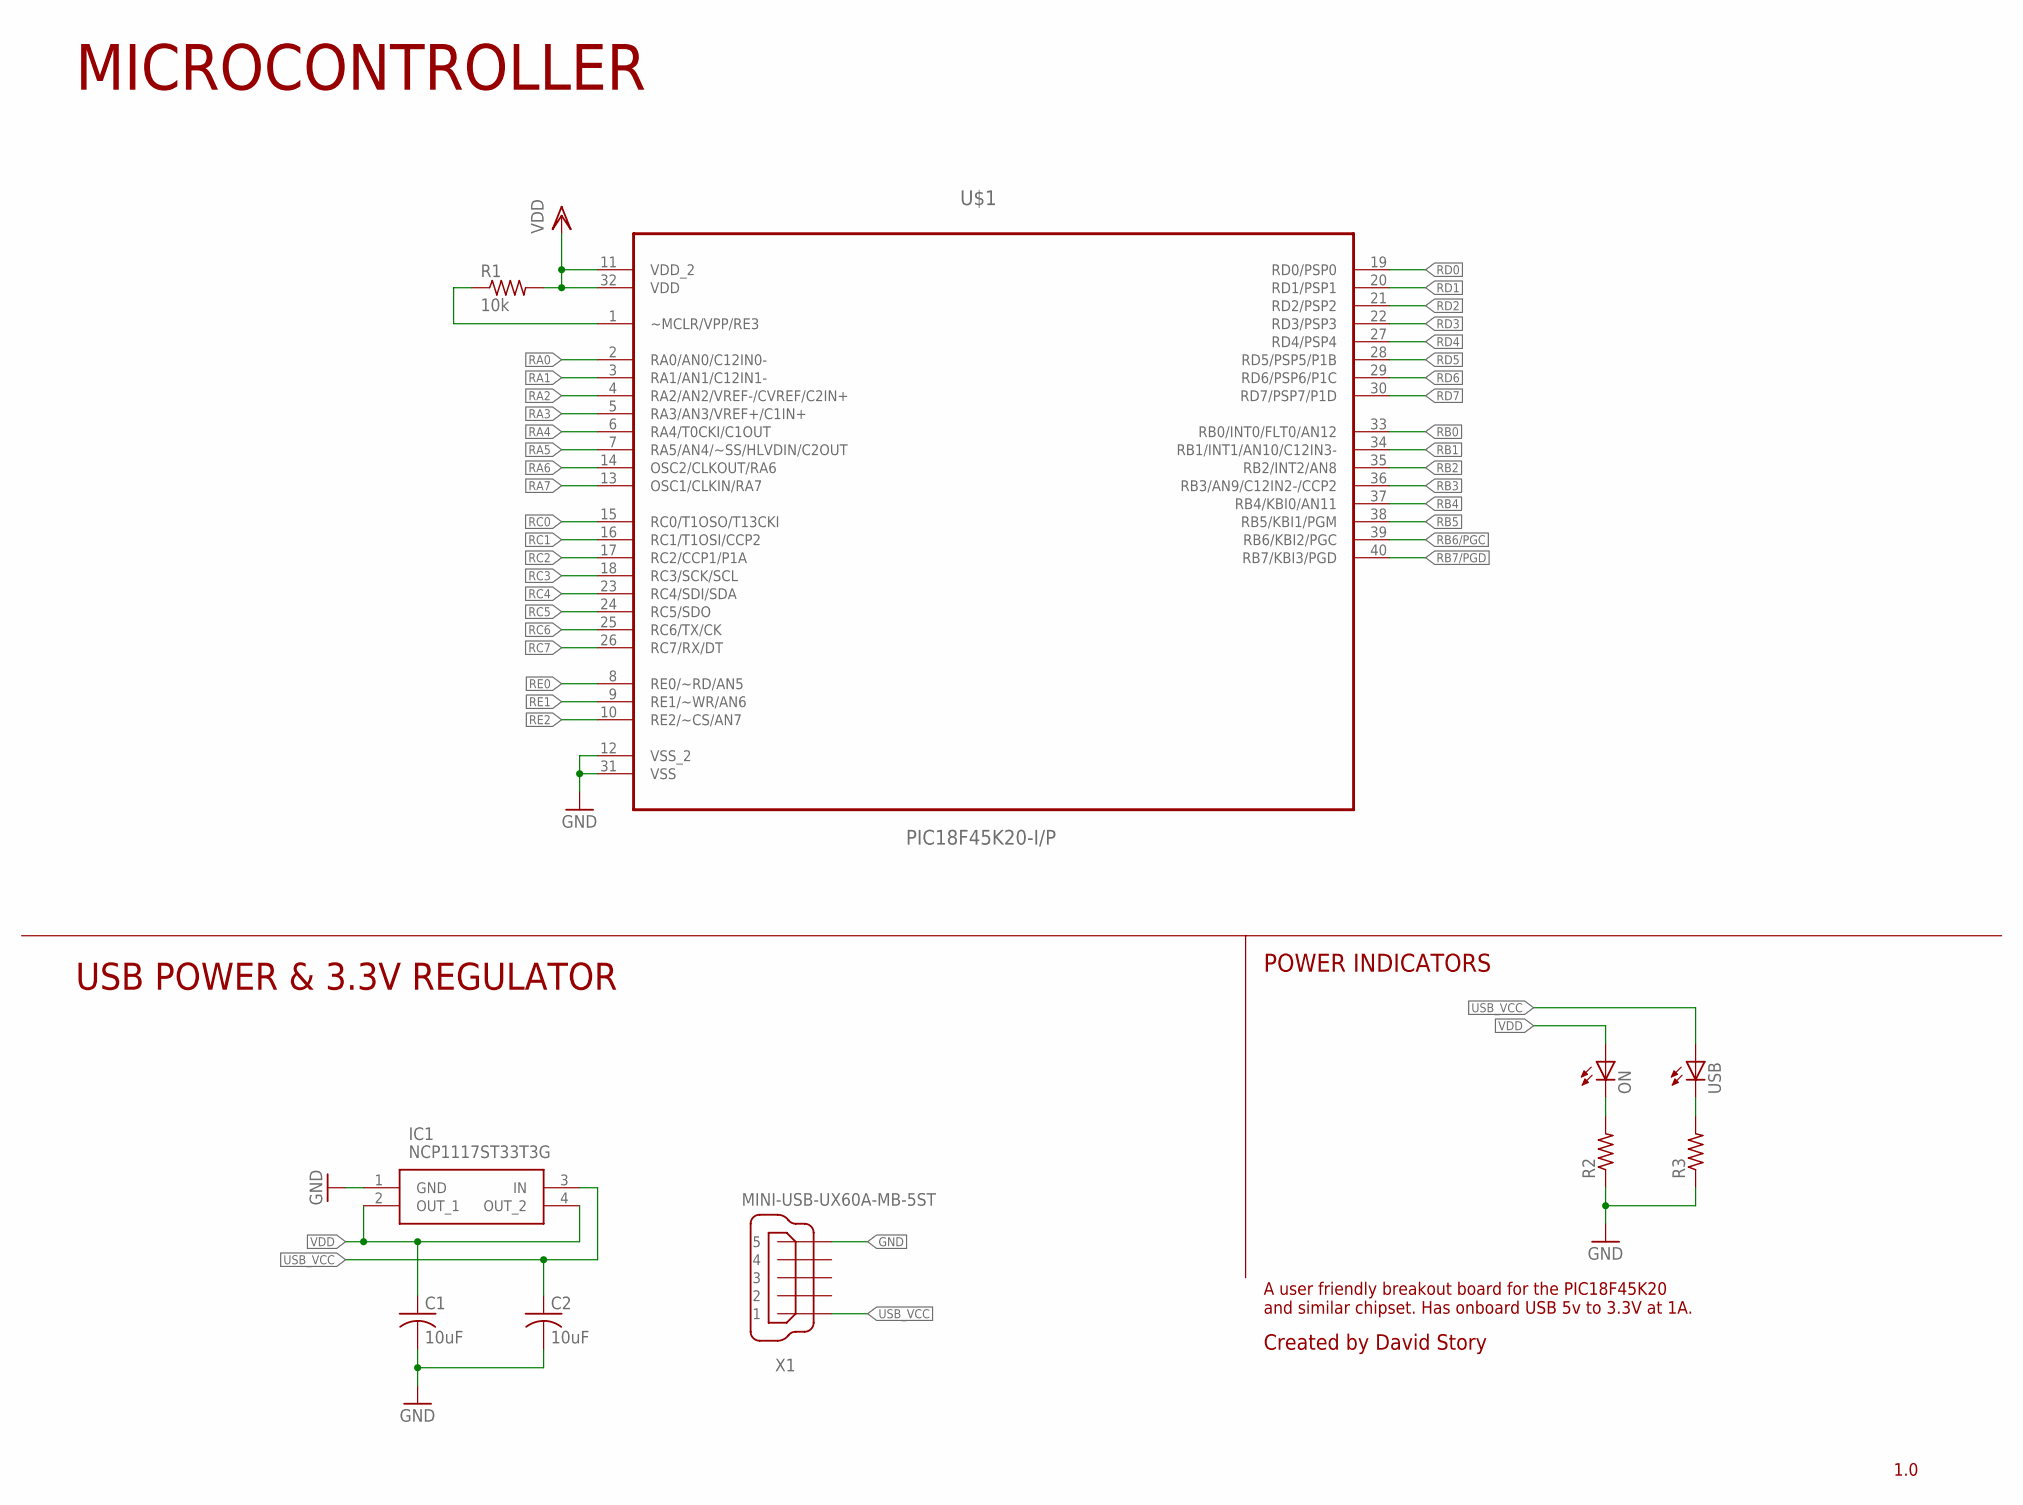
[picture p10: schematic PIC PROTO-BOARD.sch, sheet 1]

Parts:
C1, C2: 10uF; C0805
IC1: NCP1117ST33T3G; SOT230P700X180-4N
ON: LEDCHIP-LED0603; CHIP-LED0603
R1: 10k; R0805
R2, R3: R-US_R0603; R0603
U$1: PIC18F45K20-I/P; DIP254P1524X635-40
USB: LEDCHIP-LED0603; CHIP-LED0603
X1: MINI-USB-UX60A-MB-5ST; UX60A-MB-5ST

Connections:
GND: C1.2, C2.2, IC1.1 (GND), R2.1, R3.1, U$1.12 (VSS_2), U$1.31 (VSS), X1.5; also elsewhere on the board
MCLR: R1.1, U$1.1 (~MCLR/VPP/RE3); also elsewhere on the board
ON_CATHODE: ON.C, R2.2
RA0: U$1.2 (RA0/AN0/C12IN0-); also elsewhere on the board
RA1: U$1.3 (RA1/AN1/C12IN1-); also elsewhere on the board
RA2: U$1.4 (RA2/AN2/VREF-/CVREF/C2IN+); also elsewhere on the board
RA3: U$1.5 (RA3/AN3/VREF+/C1IN+); also elsewhere on the board
RA4: U$1.6 (RA4/T0CKI/C1OUT); also elsewhere on the board
RA5: U$1.7 (RA5/AN4/~SS/HLVDIN/C2OUT); also elsewhere on the board
RA6: U$1.14 (OSC2/CLKOUT/RA6); also elsewhere on the board
RA7: U$1.13 (OSC1/CLKIN/RA7); also elsewhere on the board
RB0: U$1.33 (RB0/INT0/FLT0/AN12); also elsewhere on the board
RB1: U$1.34 (RB1/INT1/AN10/C12IN3-); also elsewhere on the board
RB2: U$1.35 (RB2/INT2/AN8); also elsewhere on the board
RB3: U$1.36 (RB3/AN9/C12IN2-/CCP2); also elsewhere on the board
RB4: U$1.37 (RB4/KBI0/AN11); also elsewhere on the board
RB5: U$1.38 (RB5/KBI1/PGM); also elsewhere on the board
RB6/PGC: U$1.39 (RB6/KBI2/PGC); also elsewhere on the board
RB7/PGD: U$1.40 (RB7/KBI3/PGD); also elsewhere on the board
RC0: U$1.15 (RC0/T1OSO/T13CKI); also elsewhere on the board
RC1: U$1.16 (RC1/T1OSI/CCP2); also elsewhere on the board
RC2: U$1.17 (RC2/CCP1/P1A); also elsewhere on the board
RC3: U$1.18 (RC3/SCK/SCL); also elsewhere on the board
RC4: U$1.23 (RC4/SDI/SDA); also elsewhere on the board
RC5: U$1.24 (RC5/SDO); also elsewhere on the board
RC6: U$1.25 (RC6/TX/CK); also elsewhere on the board
RC7: U$1.26 (RC7/RX/DT); also elsewhere on the board
RD0: U$1.19 (RD0/PSP0); also elsewhere on the board
RD1: U$1.20 (RD1/PSP1); also elsewhere on the board
RD2: U$1.21 (RD2/PSP2); also elsewhere on the board
RD3: U$1.22 (RD3/PSP3); also elsewhere on the board
RD4: U$1.27 (RD4/PSP4); also elsewhere on the board
RD5: U$1.28 (RD5/PSP5/P1B); also elsewhere on the board
RD6: U$1.29 (RD6/PSP6/P1C); also elsewhere on the board
RD7: U$1.30 (RD7/PSP7/P1D); also elsewhere on the board
RE0: U$1.8 (RE0/~RD/AN5); also elsewhere on the board
RE1: U$1.9 (RE1/~WR/AN6); also elsewhere on the board
RE2: U$1.10 (RE2/~CS/AN7); also elsewhere on the board
USB_CATHODE: R3.2, USB.C
USB_VCC: C2.1, IC1.3 (IN), USB.A, X1.1
VDD: C1.1, IC1.2 (OUT_1), IC1.4 (OUT_2), ON.A, R1.2, U$1.11 (VDD_2), U$1.32 (VDD); also elsewhere on the board

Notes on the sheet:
Created by David Story
1.0
MICROCONTROLLER
USB POWER & 3.3V REGULATOR
POWER INDICATORS
A user friendly breakout board for the PIC18F45K20 and similar chipset. Has onboard USB 5v to 3.3V at 1A.

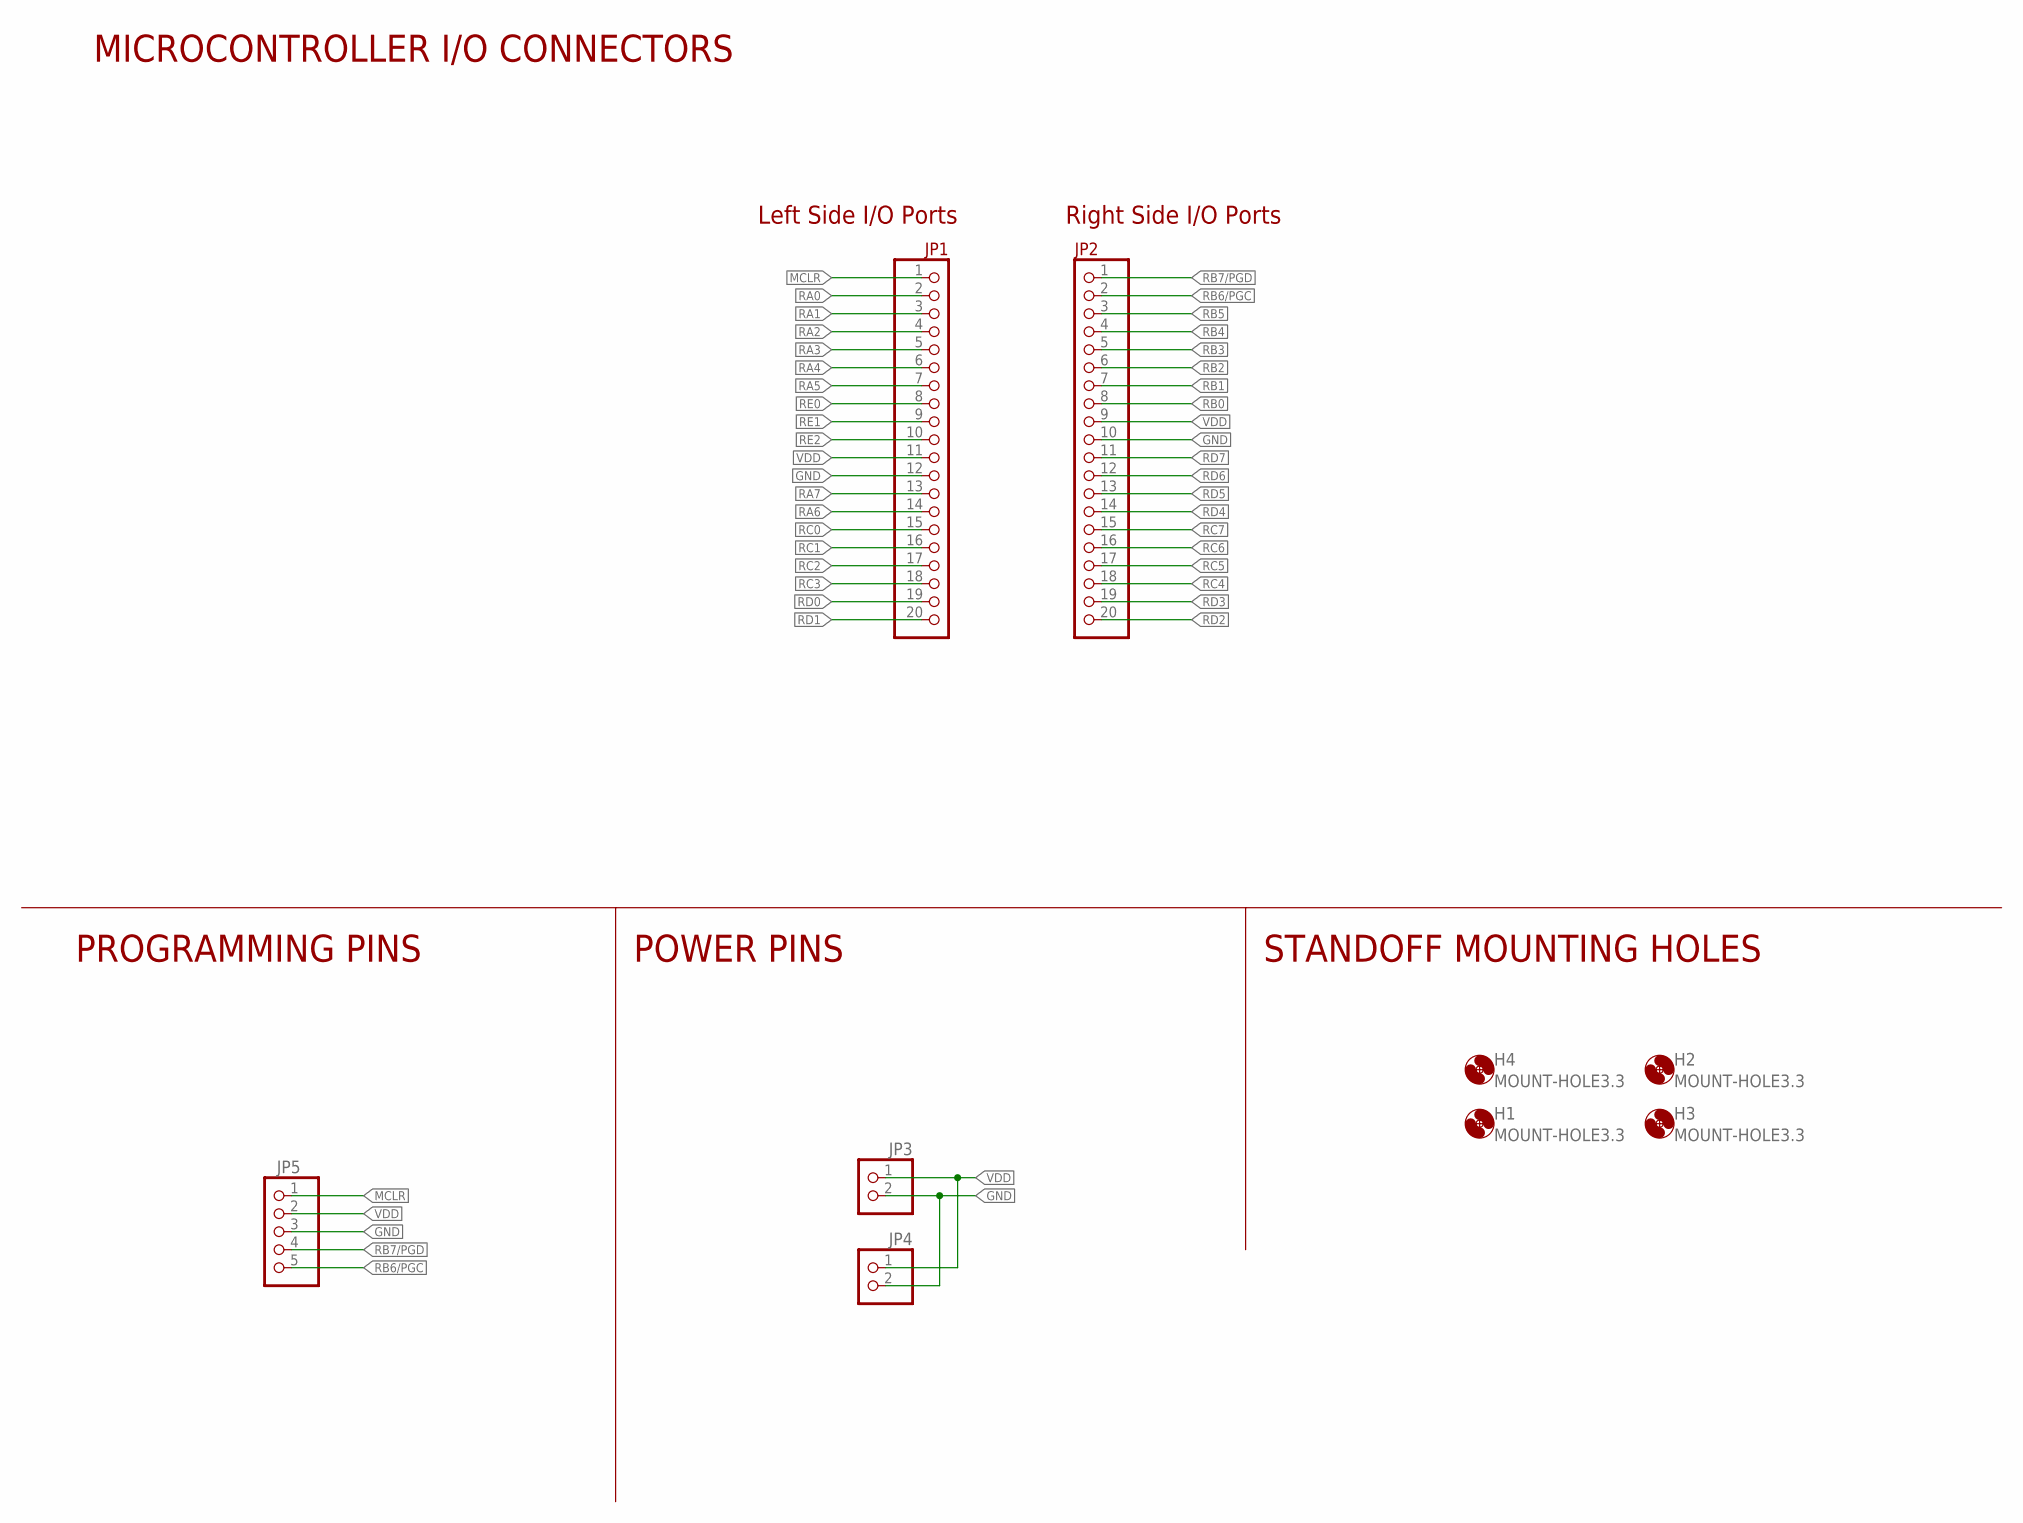
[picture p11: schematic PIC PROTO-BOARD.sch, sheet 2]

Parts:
H1, H2, H3, H4: MOUNT-HOLE3.3; 3,3
JP1, JP2: PINHD-1X20; 1X20
JP3, JP4: PINHD-1X2; 1X02
JP5: PINHD-1X5; 1X05

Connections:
GND: JP1.12, JP2.10, JP3.2, JP4.2, JP5.3; also elsewhere on the board
MCLR: JP1.1, JP5.1; also elsewhere on the board
RA0: JP1.2; also elsewhere on the board
RA1: JP1.3; also elsewhere on the board
RA2: JP1.4; also elsewhere on the board
RA3: JP1.5; also elsewhere on the board
RA4: JP1.6; also elsewhere on the board
RA5: JP1.7; also elsewhere on the board
RA6: JP1.14; also elsewhere on the board
RA7: JP1.13; also elsewhere on the board
RB0: JP2.8; also elsewhere on the board
RB1: JP2.7; also elsewhere on the board
RB2: JP2.6; also elsewhere on the board
RB3: JP2.5; also elsewhere on the board
RB4: JP2.4; also elsewhere on the board
RB5: JP2.3; also elsewhere on the board
RB6/PGC: JP2.2, JP5.5; also elsewhere on the board
RB7/PGD: JP2.1, JP5.4; also elsewhere on the board
RC0: JP1.15; also elsewhere on the board
RC1: JP1.16; also elsewhere on the board
RC2: JP1.17; also elsewhere on the board
RC3: JP1.18; also elsewhere on the board
RC4: JP2.18; also elsewhere on the board
RC5: JP2.17; also elsewhere on the board
RC6: JP2.16; also elsewhere on the board
RC7: JP2.15; also elsewhere on the board
RD0: JP1.19; also elsewhere on the board
RD1: JP1.20; also elsewhere on the board
RD2: JP2.20; also elsewhere on the board
RD3: JP2.19; also elsewhere on the board
RD4: JP2.14; also elsewhere on the board
RD5: JP2.13; also elsewhere on the board
RD6: JP2.12; also elsewhere on the board
RD7: JP2.11; also elsewhere on the board
RE0: JP1.8; also elsewhere on the board
RE1: JP1.9; also elsewhere on the board
RE2: JP1.10; also elsewhere on the board
VDD: JP1.11, JP2.9, JP3.1, JP4.1, JP5.2; also elsewhere on the board

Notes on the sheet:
Left Side I/O Ports
Right Side I/O Ports
PROGRAMMING PINS
POWER PINS
STANDOFF MOUNTING HOLES
MICROCONTROLLER I/O CONNECTORS

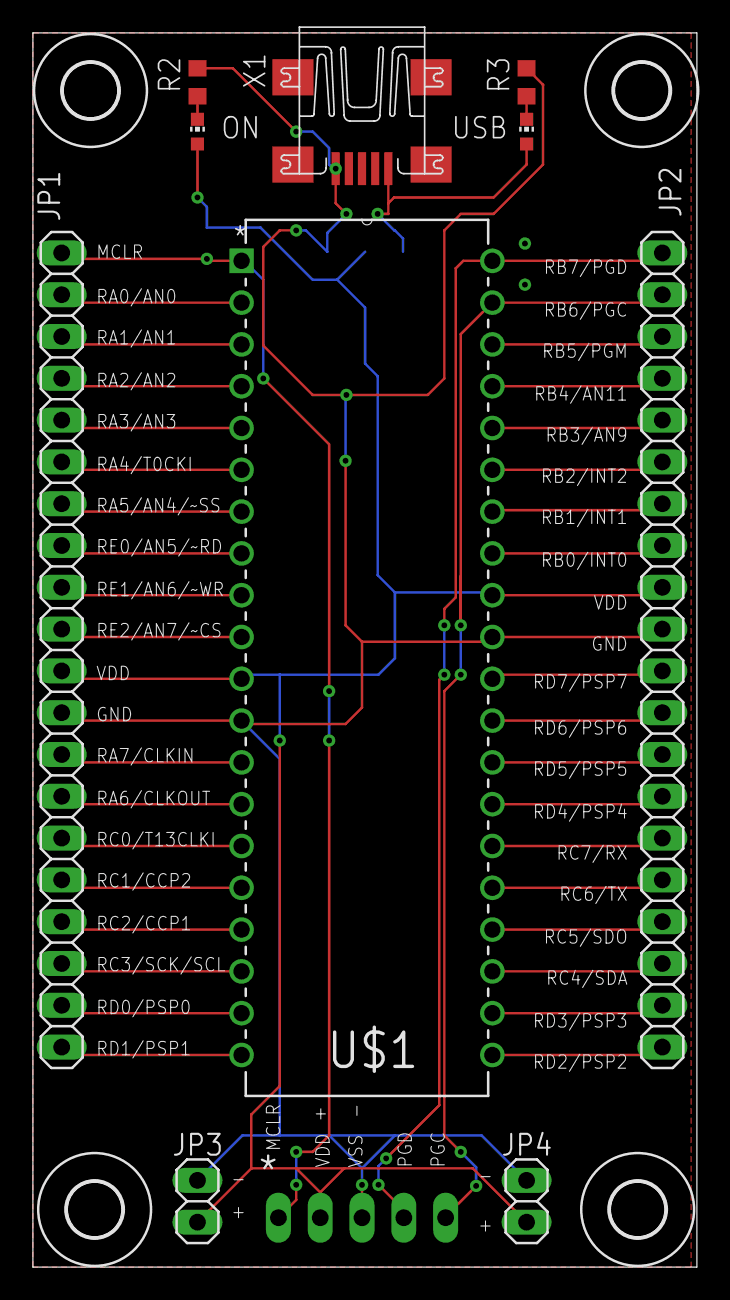
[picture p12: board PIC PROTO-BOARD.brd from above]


Board: 2 copper layers, 40.4 x 75.0 mm, 19 parts (5 on the bottom side), 41 nets.

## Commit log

2019-02-07 Added some board files
    [PIC PROTO-BOARD.brd, PIC PROTO-BOARD.sch, PIC SENSOR-BOARD.brd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]
2019-02-10 Added Sensor Board
    [PIC SENSOR-BOARD.brd, PIC SENSOR-BOARD.sch]
2019-03-03 Added SMD verison of microcontroller board
    [PIC PROTO-BOARD-SMD.brd, PIC PROTO-BOARD-SMD.sch]

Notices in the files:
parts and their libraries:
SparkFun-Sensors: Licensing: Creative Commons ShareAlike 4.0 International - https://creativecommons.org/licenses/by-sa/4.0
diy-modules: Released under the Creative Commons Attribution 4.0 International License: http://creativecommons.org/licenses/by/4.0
